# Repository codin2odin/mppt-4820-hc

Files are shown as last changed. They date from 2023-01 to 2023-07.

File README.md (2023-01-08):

# MPPT charge controller with HS load switch and CAN

 Development ongoing.

Schematic: [PDF file](build/mppt-4820-hc_schematic.pdf)

Bill of Materials: [CSV file](build/mppt-4820-hc_bom(hv_supply,can).csv)

Firmware repository: [charge-controller-firmware](https://github.com/codin2odin/charge-controller-firmware)

This charge controller design is modified version of [mppt-2420-hc](https://github.com/LibreSolar/mppt-2420-hc) with goal of adding support for 36v & 48v battery systems.

## Features

- Solar input terminal
    - Max. 85V (100V MOSFETs used)
    - DC/DC converter inductor current max. 20A
- Battery output terminal
    - 10 V - 60 V (supporting 12v & 24v & 36v & 48v battery systems)
    - Max. current: 20A (limited by inductor current)
- Load terminal: 20A
- New STM32G431 ARM MCU with advanced digital power conversion features
- Expandable via Olimex Universal Extension Connector (UEXT)
- Two bi-color (red/green) LEDs for status indication. Additional user interface can be included in separate PCB in front panel housing and connected via UEXT
- CAN interface via RJ45 connectors

## Mechanical design

- TO-220 MOSFETs can be screwed to large heat sink at the back

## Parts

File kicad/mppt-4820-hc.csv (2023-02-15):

Source: | /home/strigis/repositories/mppt-4820-hc/kicad/mppt-2420-hc.kicad_sch
Date: | Wed 25 Jan 2023 10:38:43 AM CET
Tool: | Eeschema 6.0.10-86aedd382b~118~ubuntu20.04.1
Generator: | /usr/share/kicad/plugins/bom_csv_grouped_by_value_with_fp.py
Component Count: | 141
Ref | Qnty | Value | Cmp name | Footprint | Description | Vendor
C1, C2, | 2 | 560µF | CP-LibreSolar | Capacitor_THT:CP_Radial_D18.0mm_P7.50mm
C3, C18, | 2 | 1µF | C | LibreSolar:C_0805_2012 | Unpolarized capacitor
C4, | 1 | 100nF | C | LibreSolar:C_0805_2012 | Unpolarized capacitor
C5, C27, | 2 | 680µF | CP-LibreSolar | Capacitor_THT:CP_Radial_D10.0mm_P5.00mm
C6, | 1 | 2.2nF | C | LibreSolar:C_0603_1608 | Unpolarized capacitor
C7, C9, C10, C13, C20, C22, C24, C29, C30, C31, C32, C48, | 12 | 100nF | C | LibreSolar:C_0603_1608 | Unpolarized capacitor
C8, C14, C16, C17, C25, C34, | 6 | 10nF | C | LibreSolar:C_0603_1608 | Unpolarized capacitor
C11, C15, | 2 | 1nF | C | LibreSolar:C_0603_1608 | Unpolarized capacitor
C12, C33, C39, C49, | 4 | 2.2µF | C | LibreSolar:C_0603_1608 | Unpolarized capacitor
C19, | 1 | 4.7µF | C | LibreSolar:C_1210_3225 | Unpolarized capacitor
C21, C23, | 2 | 10µF | C | LibreSolar:C_0805_2012 | Unpolarized capacitor
C40, | 1 | 1µF | C | LibreSolar:C_0603_1608 | Unpolarized capacitor
C41, | 1 | 4.7µF | C | LibreSolar:C_0603_1608 | Unpolarized capacitor
C42, C44, | 2 | 0.22µF | C-LibreSolar | Capacitor_THT:C_Rect_L7.2mm_W3.5mm_P5.00mm_FKS2_FKP2_MKS2_MKP2
D1, | 1 | SS16FP | D_Schottky | Diode_SMD:D_PowerDI-123 | Diode Schottky
D2, D6, | 2 | NRVTS260ESFT1G | D_Schottky-LibreSolar | Diode_SMD:D_SOD-123
D4, | 1 | BAS70-04 | BAS40-04 | Package_TO_SOT_SMD:SOT-23 | 40V 0.2A Dual Small Signal Schottky Diodes
D5, | 1 | 12V | D_Zener | Diode_SMD:D_SOT-23_ANK | Diode zener
D7, D14, D15, | 3 | SS14FL | D_Schottky | Diode_SMD:D_SOD-123 | Diode Schottky
D16, | 1 | 1N4148 | D | LibreSolar:D_SOD-123 | Diode
F1, | 1 | 25A | Fuse_PlugIn-LibreSolar | LibreSolar:NULL
F2, F3, | 2 | 500mA | Polyfuse_Small | Fuse:Fuse_1206_3216Metric | Resettable fuse, polymeric positive temperature coefficient, small symbol
FID1, FID2, FID3, | 3 | Fiducial | Fiducial | LibreSolar:Fiducial_0.7mm | Fiducial Marker
J1, J2, | 2 | MKDS 5/ 2-9,5 | Screw_Terminal_1x02 | LibreSolar:Phoenix_Contact_MKDS_5-2-9,5
J4, J5, | 2 | 8P8C | 8P8C | LibreSolar:RJ45_8P8C | RJ connector, 8P8C (8 positions 8 connected), RJ31/RJ32/RJ33/RJ34/RJ35/RJ41/RJ45/RJ49/RJ61
J7, | 1 | UEXT | UEXT | LibreSolar:Box_Header_2x05x2.54mm_Straight | Olimex UEXT connector (2x5 box header)
JP1, | 1 | Jumper_NC_Small | Jumper_NC_Small-LibreSolar | Connector_PinHeader_2.54mm:PinHeader_1x02_P2.54mm_Vertical
L1, | 1 | 53µH | L | LibreSolar:Inductor_Toroid_D32.8mm_4mm2 | Inductor
L2, | 1 | 4.7µH | L_Small | Inductor_SMD:L_0805_2012Metric | Inductor, small symbol
L3, | 1 | 47µH | L_Small | LibreSolar:Bourns_SRN6045TA | Inductor, small symbol
LED1, LED2, | 2 | LED_Dual_PLCC4 | LED_Dual_CACA_BackToBack-LibreSolar | LED_SMD:LED_Avago_PLCC4_3.2x2.8mm_CW
LOGO1, | 1 | LIBRE_SOLAR | LibreSolar_Logo | LibreSolar:LIBRESOLAR_LOGO
LOGO2, | 1 | OPEN_HARDWARE | Logo_Open_Hardware_Small | Symbol:OSHW-Logo_5.7x6mm_SilkScreen | Open Hardware logo, small
MK1, MK2, MK3, MK4, | 4 | Mounting_Hole | MountingHole | MountingHole:MountingHole_3.2mm_M3 | Mounting Hole without connection
P1, | 1 | CONN_01X02 | Conn_01x02 | Connector_PinHeader_2.54mm:PinHeader_1x02_P2.54mm_Vertical | Generic connector, single row, 01x02, script generated (kicad-library-utils/schlib/autogen/connector/)
Q1, Q2, Q3, | 3 | IPA045N10N3G | Q_NMOS_GDS | LibreSolar:TO-220-3_Horizontal_BottomHeatsink | N-MOSFET transistor, gate/drain/source
R1, R2, R3, R5, | 4 | 3R3 | R | LibreSolar:R_0805_2012 | Resistor
R4, R12, | 2 | 4R7 | R | LibreSolar:R_1206_3216 | Resistor
R6, | 1 | 2m | R | LibreSolar:R_Bourns_CRE2512 | Resistor
R7, R16, R24, R64, | 4 | 10k | R | LibreSolar:R_0603_1608 | Resistor
R11, | 1 | 120R | R-LibreSolar | Resistor_SMD:R_1206_3216Metric
R13, R17, R22, R30, | 4 | 100k | R | LibreSolar:R_0603_1608 | Resistor
R14, R20, R21, R31, | 4 | 2.2k | R | LibreSolar:R_0603_1608 | Resistor
R15, R56, | 2 | 1M | R | LibreSolar:R_0603_1608 | Resistor
R18, | 1 | 5.6k | R | LibreSolar:R_0603_1608 | Resistor
R23, | 1 | 33k | R | LibreSolar:R_0603_1608 | Resistor
R25, R26, R29, | 3 | 1k | R | LibreSolar:R_0603_1608 | Resistor
R27, R28, R32, R40, | 4 | 47R | R | LibreSolar:R_0603_1608 | Resistor
RT1, | 1 | 10k | Thermistor_NTC | Capacitor_THT:C_Disc_D3.8mm_W2.6mm_P2.50mm | Temperature dependent resistor, negative temperature coefficient
RV2, | 1 | 82V | Varistor | Varistor:RV_Disc_D12mm_W4.3mm_P7.5mm | Voltage dependent resistor
SWD1, | 1 | ST_Nucleo_SWD | ST_Nucleo_SWD_5p-LibreSolar | Connector_PinHeader_2.54mm:PinHeader_1x05_P2.54mm_Vertical
T1, T3, T10, | 3 | BC846B | BC846 | LibreSolar:SOT-23 | 0.1A Ic, 65V Vce, NPN Transistor, SOT-23
T4, | 1 | BC856B | BC856 | LibreSolar:SOT-23 | 0.1A Ic, 65V Vce, PNP Transistor, SOT-23
TP1, TP3, TP4, TP5, TP6, TP7, TP8, TP9, TP10, TP11, TP12, TP13, TP14, TP15, TP17, TP18, TP19, TP20, TP21, TP22, | 20 | 1.5mm | TestPoint | TestPoint:TestPoint_Pad_D1.5mm | test point
U1, | 1 | LM5107 | LM5107 | LibreSolar:SOIC-8_3.9x4.9mm_Pitch1.27mm
U2, | 1 | STM32G431CBTx | STM32G431CBTx-LibreSolar | Package_QFP:LQFP-48_7x7mm_P0.5mm
U3, | 1 | MPQ8112 | MPQ8112 | Package_TO_SOT_SMD:TSOT-23-6
U4, | 1 | LMR16006X | LMR16006 | LibreSolar:SOT-23-6 | SIMPLE SWITCHER® 4V to 60V, 600mA Step-Down Regulator with Low Iq
U6, | 1 | W25Q80DVS | W25Q128JVS | LibreSolar:SOIC-8_3.9x4.9mm_Pitch1.27mm | 128Mb Serial Flash Memory, Standard/Dual/Quad SPI, SOIC-8
U7, | 1 | TCAN334 | TCAN334 | LibreSolar:SOIC-8_3.9x4.9mm_Pitch1.27mm | High-Speed CAN Transceiver, 1Mbps, 3.3V supply, low power standby mode, shutdown mode, SOT-23-8/SOIC-8
XF1, | 1 | Fuse_Holder | Fuse_Holder-LibreSolar | LibreSolar:Eaton_S-4000
Y1, | 1 | 8MHz | Resonator | LibreSolar:Resonator_Murata_CSTNE | Two pin crystal

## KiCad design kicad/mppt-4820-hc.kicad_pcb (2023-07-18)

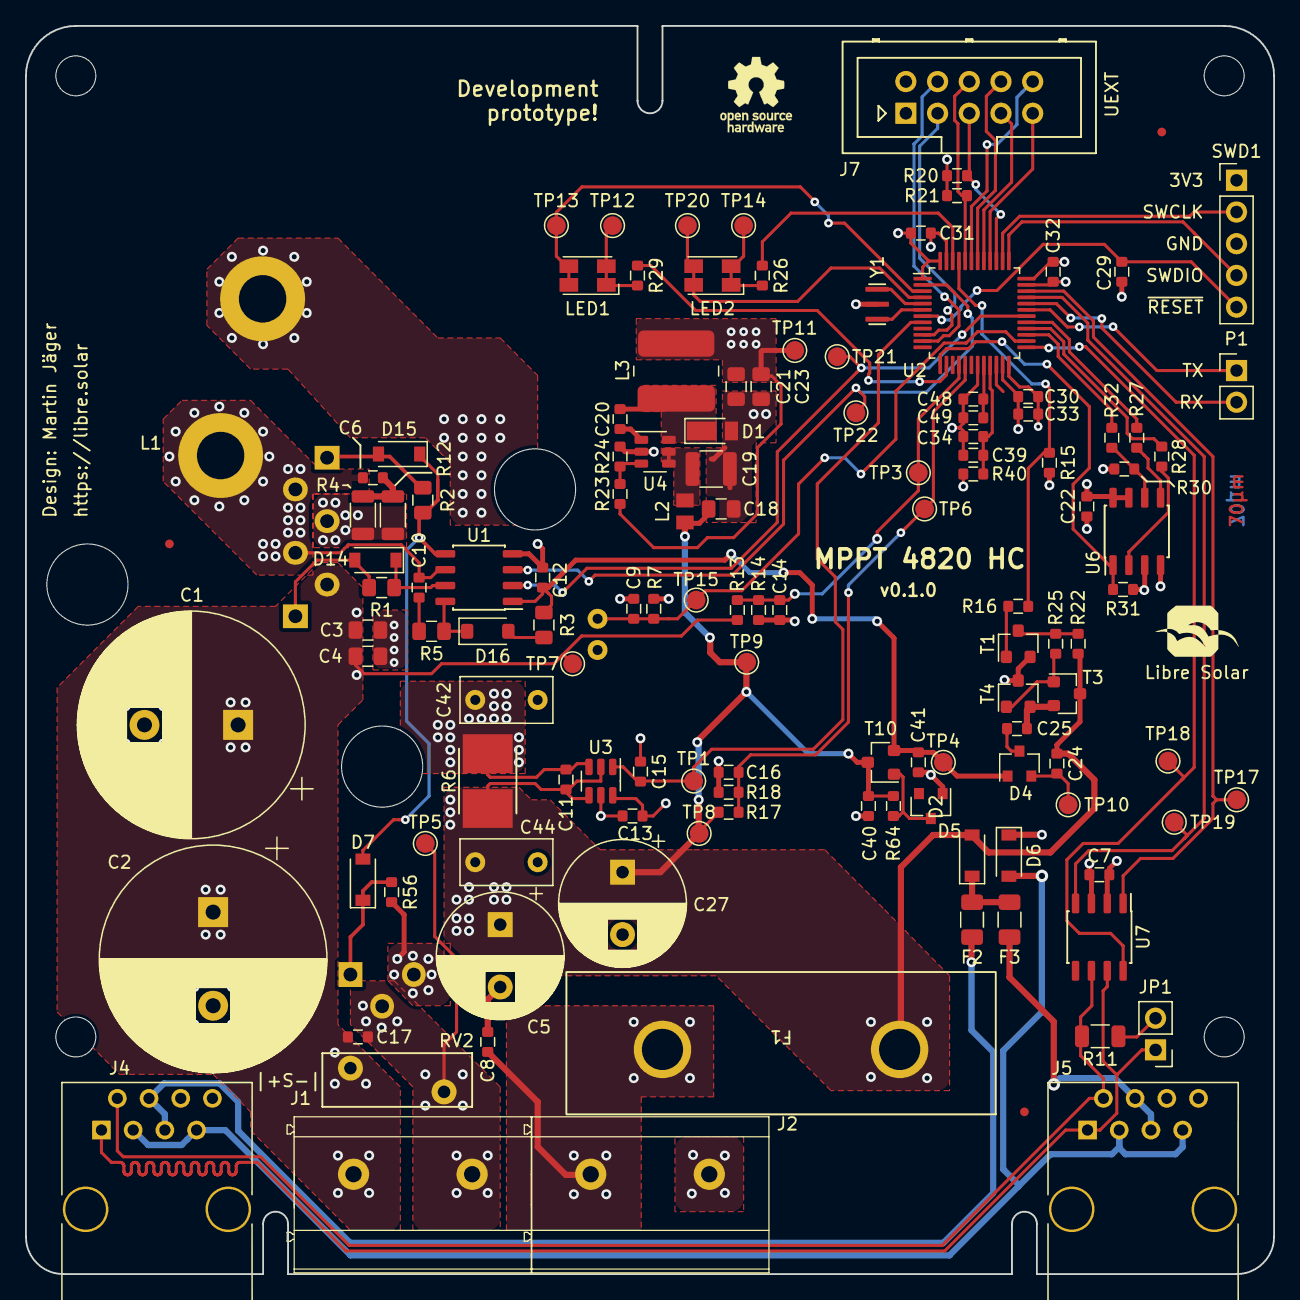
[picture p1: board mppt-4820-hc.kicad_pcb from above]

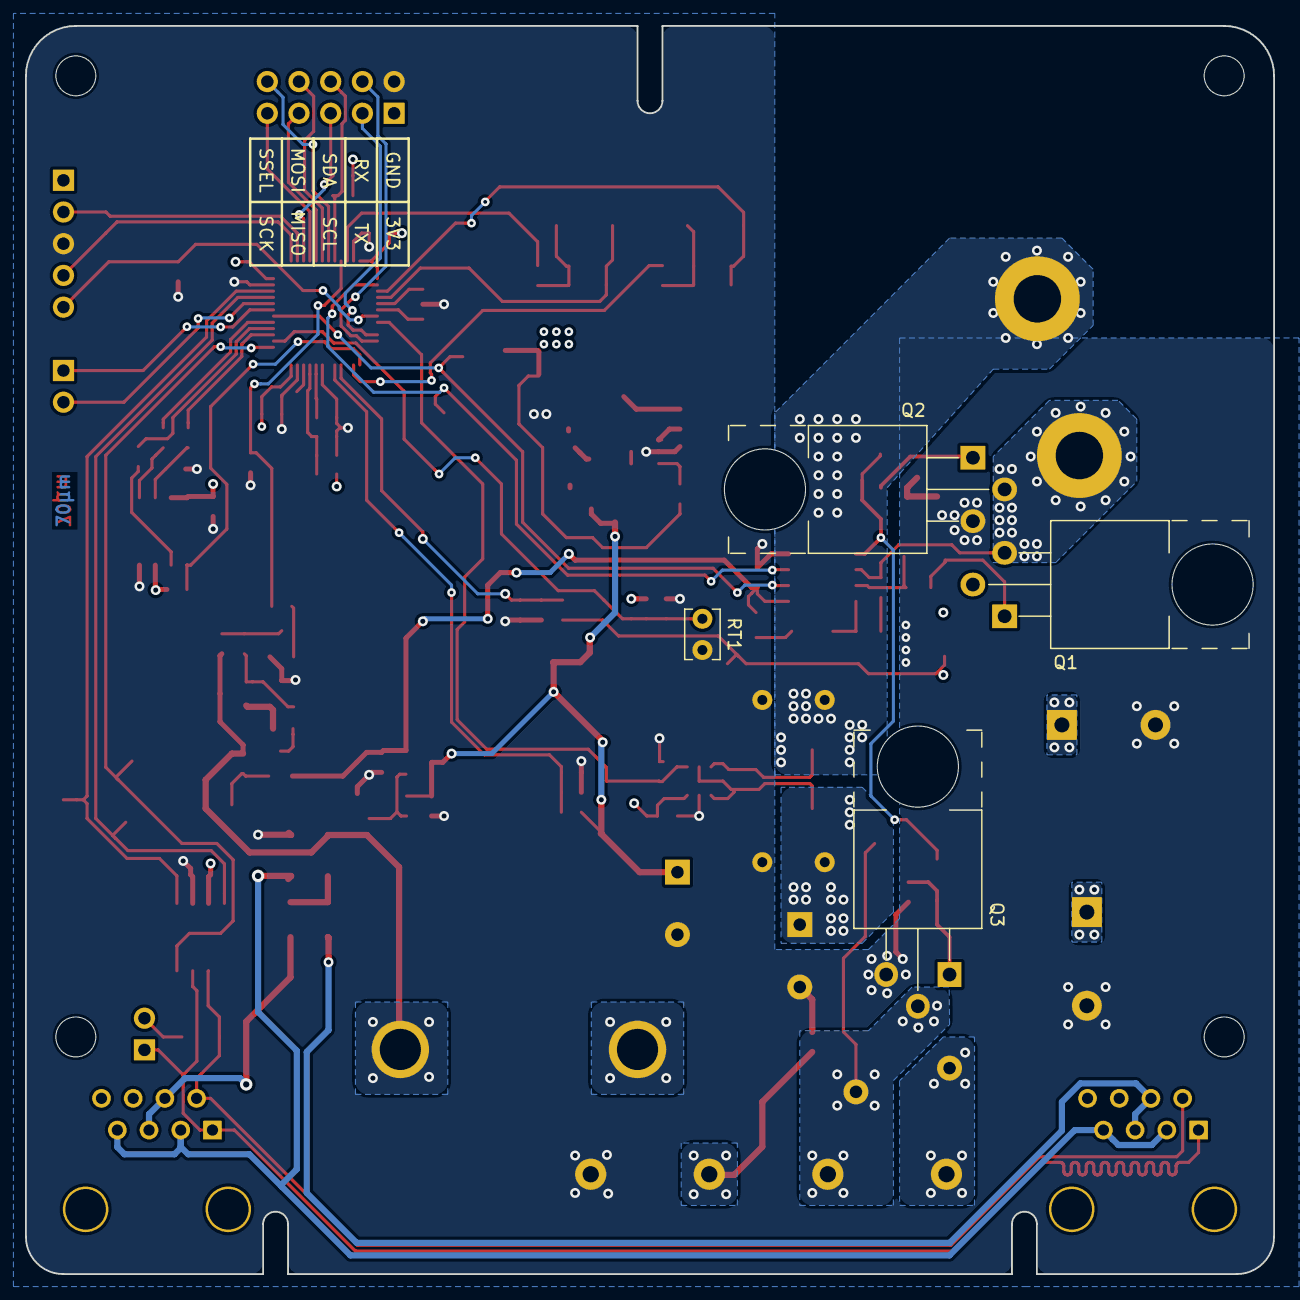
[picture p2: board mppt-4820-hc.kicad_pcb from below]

Board: 4 copper layers, 100.0 x 100.0 mm, 140 parts (4 on the bottom side), 76 nets.

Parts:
C1, C2: 560µF; CP_Radial_D18.0mm_P7.50mm
C3, C18: 1µF; C_0805_2012
C4: 100nF; C_0805_2012
C5, C27: 680µF; CP_Radial_D10.0mm_P5.00mm
C6: 2.2nF; C_0603_1608
C7, C9, C10, C13, C20, C22, C24, C29, C30, C31, C32, C48: 100nF; C_0603_1608
C8, C14, C16, C17, C25, C34: 10nF; C_0603_1608
C11, C15: 1nF; C_0603_1608
C12, C33, C39, C49: 2.2µF; C_0603_1608
C19: 4.7µF; C_1210_3225
C21, C23: 10µF; C_0805_2012
C40: 1µF; C_0603_1608
C41: 4.7µF; C_0603_1608
C42, C44: 0.22µF; C_Rect_L7.2mm_W3.5mm_P5.00mm_FKS2_FKP2_MKS2_MKP2
D1: SS16FP; D_PowerDI-123
D2, D6: NRVTS260ESFT1G; D_SOD-123
D4: BAS70-04; SOT-23
D5: 12V; D_SOT-23_ANK
D7, D14, D15: SS14FL; D_SOD-123
D16: 1N4148; D_SOD-123
F1: 25A; Eaton_S-4000
F2, F3: 500mA; Fuse_1206_3216Metric
FID1, FID2, FID3: Fiducial; Fiducial_0.7mm
J1, J2: MKDS 5/ 2-9,5; Phoenix_Contact_MKDS_5-2-9,5
J4, J5: 8P8C; RJ45_8P8C
J7: UEXT; Box_Header_2x05x2.54mm_Straight
JP1: Jumper_NC_Small; PinHeader_1x02_P2.54mm_Vertical
L1: 53µH; Inductor_Toroid_D32.8mm_4mm2
L2: 4.7µH; L_0805_2012Metric
L3: 47µH; Bourns_SRN6045TA
LED1, LED2: LED_Dual_PLCC4; LED_Avago_PLCC4_3.2x2.8mm_CW
LOGO1: LIBRE_SOLAR; LIBRESOLAR_LOGO
LOGO2: OPEN_HARDWARE; OSHW-Logo_5.7x6mm_SilkScreen
MK1, MK2, MK3, MK4: Mounting_Hole; MountingHole_3.2mm_M3
P1: CONN_01X02; PinHeader_1x02_P2.54mm_Vertical
Q1, Q2, Q3: IPA045N10N3G; TO-220-3_Horizontal_BottomHeatsink
R1, R2, R3, R5: 3R3; R_0805_2012
R4, R12: 4R7; R_1206_3216
R6: 2m; R_Bourns_CRE2512
R7, R16, R24, R64: 10k; R_0603_1608
R11: 120R; R_1206_3216Metric
R13, R17, R22, R30: 100k; R_0603_1608
R14, R20, R21, R31: 2.2k; R_0603_1608
R15, R56: 1M; R_0603_1608
R18: 5.6k; R_0603_1608
R23: 33k; R_0603_1608
R25, R26, R29: 1k; R_0603_1608
R27, R28, R32, R40: 47R; R_0603_1608
RT1: 10k; C_Disc_D3.8mm_W2.6mm_P2.50mm
RV2: 82V; RV_Disc_D12mm_W4.3mm_P7.5mm
SWD1: ST_Nucleo_SWD; PinHeader_1x05_P2.54mm_Vertical
T1, T3, T10: BC846B; SOT-23
T4: BC856B; SOT-23
TP1, TP3, TP4, TP5, TP6, TP7, TP8, TP9, TP10, TP11, TP12, TP13, TP14, TP15, TP17, TP18, TP19, TP20, TP21, TP22: 1.5mm; TestPoint_Pad_D1.5mm
U1: LM5107; SOIC-8_3.9x4.9mm_Pitch1.27mm
U2: STM32G431CBTx; LQFP-48_7x7mm_P0.5mm
U3: MPQ8112; TSOT-23-6
U4: LMR16006X; SOT-23-6
U6: W25Q80DVS; SOIC-8_3.9x4.9mm_Pitch1.27mm
U7: TCAN334; SOIC-8_3.9x4.9mm_Pitch1.27mm
Y1: 8MHz; Resonator_Murata_CSTNE

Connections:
+3V3: C7.1, C13.1, C21.1, C22.1, C23.1, C30.1, C31.1, C32.1, C33.1, J7.1 (3V3), L3.2, R7.1, R20.2, R21.2, R23.1, R31.2, R40.2, SWD1.1 (VCC), TP11.1, U2.1 (VBAT), U2.24 (VDD), U2.36 (VDD), U2.48 (VDD), U3.6 (EN), U6.3 (IO2), U6.7 (IO3), U6.8 (VCC), U7.3 (VCC)
+12V: C12.1, C41.1, D4.1, R3.2, T10.2 (E), TP4.1, U1.1 (VDD)
/BAT+: C8.1, F1.2, J2.1
/CAN/CAN_PWR1: F2.1, J4.4, J4.5
/CAN/CAN_PWR2: F3.1, J5.4, J5.5
/CAN/CAN_RX: TP19.1, U2.33 (PA11), U7.4 (RXD)
/CAN/CAN_STB: TP18.1, U2.25 (PB11), U7.8 (STB)
/CAN/CAN_TX: TP17.1, U2.34 (PA12), U7.1 (TXD)
/CAN_GND: D6.2 (A), J4.3, J4.7, J5.3, J5.7
/CAN_H: J4.1, J5.1, JP1.1, U7.7 (CANH)
/CAN_L: J4.2, J5.2, R11.2, U7.6 (CANL)
/DC/DC/HS_DRV: D14.1 (K), R1.2, U1.7 (HO)
/DC/DC/I_DCDC: C15.1, TP1.1, U2.8 (PA0), U3.1 (OUT)
/DC/DC/LS_DRV: D7.2 (A), D15.1 (K), R2.2, U1.5 (LO)
/DC/DC/PWM_HS: TP21.1, U1.2 (HI), U2.30 (PA8)
/DC/DC/PWM_LS: TP22.1, U1.3 (LI), U2.2 (PC13)
/DC/DC/SHUNT_DCDC_P: C11.1, C42.1, L1.2, R6.2, U3.3 (+)
/DC/DC/SW_NODE: C6.1, C10.2, L1.1, Q1.3 (S), Q2.2 (D), U1.6 (HS)
/DC/DC/V_DCDC_H: C14.1, R13.2, R14.1, TP3.1, U2.16 (PB0)
/DC/DC/V_DCDC_L: C16.1, R17.2, R18.1, TP6.1, U2.17 (PB1)
/DCDC_HV+: C1.1, C2.1, C3.1, C4.1, C17.1, J1.1, Q1.2 (D), R13.1, RV2.1, TP7.1
/DCDC_HV-: C17.2, J1.2, Q3.2 (D), RV2.2, TP5.1
/MCU/ADC1_IN11: C9.1, R7.2, RT1.1, TP15.1, U2.26 (PB12)
/MCU/GPIOC_14: LED1.2 (K1), LED1.3 (A2), TP13.1, U2.3 (PC14-OSC32_IN)
/MCU/GPIOC_15: LED2.2 (K1), LED2.3 (A2), TP20.1, U2.4 (PC15-OSC32_OUT)
/MCU/I2C1_SCL: J7.5 (SCL), R20.1, U2.39 (PA15)
/MCU/I2C1_SDA: J7.6 (SDA), R21.1, U2.44 (PB7)
/MCU/OSC_IN: U2.5 (PF0-OSC_IN), Y1.3
/MCU/OSC_OUT: U2.6 (PF1-OSC_OUT), Y1.1
/MCU/SPI1_MISO: J7.7 (MISO), U2.41 (PB4)
/MCU/SPI1_MOSI: J7.8 (MOSI), U2.42 (PB5)
/MCU/SPI1_SCK: J7.9 (SCK), U2.40 (PB3)
/MCU/SPI1_SSEL: J7.10 (SSEL), U2.43 (PB6)
/MCU/SPI2_CS: R31.1, U2.13 (PA5), U6.1 (~CS)
/MCU/SPI2_MISO: R28.1, U2.28 (PB14)
/MCU/SPI2_MOSI: R27.1, U2.29 (PB15)
/MCU/SPI2_SCK: R32.2, U2.27 (PB13)
/MCU/SWCLK: SWD1.2 (SWCLK), U2.38 (PA14)
/MCU/SWDIO: SWD1.4 (SWDIO), U2.37 (PA13)
/MCU/TIM8_CH2: R15.2, R16.2, U2.45 (PB8-BOOT0)
/MCU/TIM16_CH1: R29.2, U2.14 (PA6)
/MCU/TIM17_CH1: R26.2, U2.46 (PB9)
/MCU/USART1_RX: P1.2, U2.32 (PA10)
/MCU/USART1_TX: P1.1, U2.31 (PA9)
/MCU/USART2_RX: J7.4 (RXD), U2.11 (PA3)
/MCU/USART2_TX: J7.3 (TXD), U2.10 (PA2)
/MCU/~RESET: C29.1, SWD1.5 (NRST), U2.7 (NRST)
/Power supply/CP_OUT: C24.1, D4.2, TP10.1
/Power supply/CP_SW: C25.2, T3.2 (E), T4.2 (E)
GND: C1.2, C2.2, C3.2, C4.2, C5.2, C7.2, C8.2, C9.2, C12.2, C13.2, C14.2, C15.2, C16.2, C18.2, C19.2, C21.2, C22.2, C23.2, C27.2, C29.2, C30.2, C31.2, C32.2, C33.2, C34.2, C39.2, C40.2, C41.2, C42.2, C44.1, C48.2, C49.2, D1.2 (A), D5.2 (A), D6.1 (K), J2.2, J7.2 (GND), Q2.3 (S), Q3.3 (S), R4.1, R12.1, R14.2, R15.1, R18.2, R24.2, R30.1, R56.2, RT1.2, SWD1.3 (GND), T1.2 (E), T4.3 (C), U1.4 (VSS), U2.19 (VSSA), U2.23 (VSS), U2.35 (VSS), U2.47 (VSS), U3.5 (GND), U4.2 (GND), U6.4 (GND), U7.2 (GND), Y1.2
unnamed: C6.2, R4.2, R12.2
unnamed: C10.1, R5.2
unnamed: C25.1, D4.3
unnamed: C20.2, D1.1 (K), L3.1, U4.6 (SW)
unnamed: D2.1 (K), F2.2, F3.2
unnamed: D5.1 (K), R64.1, T10.1 (B)
unnamed: D7.1 (K), Q3.1 (G), R56.1
unnamed: D14.2 (A), Q1.1 (G), R1.1
unnamed: D15.2 (A), Q2.1 (G), R2.1
unnamed: D16.2 (A), R3.1
unnamed: D16.1 (K), R5.1, U1.8 (HB)
unnamed: JP1.2, R11.1
unnamed: LED1.1 (A1), LED1.4 (K2), R29.1, TP12.1
unnamed: LED2.1 (A1), LED2.4 (K2), R26.1, TP14.1
unnamed: R16.1, T1.1 (B)
unnamed: R22.1, R25.1, T1.3 (C)
unnamed: R25.2, T3.1 (B), T4.1 (B)
unnamed: C20.1, U4.1 (CB)
unnamed: C19.1, L2.2, U4.4 (EN), U4.5 (Vin)
unnamed: R23.2, R24.1, U4.3 (FB)
unnamed: R30.2, R32.1, U6.6 (CLK)
unnamed: R27.2, U6.5 (DI(IO0))
unnamed: R28.2, U6.2 (DO(IO1))
VBUS: C5.1, C11.2, C18.1, C24.2, C27.1, C40.1, C44.2, D2.2 (A), F1.1, L2.1, R6.1, R17.1, R22.2, R64.2, T3.3 (C), T10.3 (C), TP8.1, TP9.1, U3.2 (-), U3.4 (V+)
VDDA: C34.1, C39.1, R40.1, U2.21 (VDDA)
VREF: C48.1, C49.1, U2.20 (VREF+)

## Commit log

2023-01-07 initial 48v LV side kicad update:
    migrated files to KiCad 6
    replaced LV side current amp ic (60v)
    replaced caps in LV (63v)
    removed HV rail supply option
    [can.kicad_sch, can.sch, dcdc.kicad_sch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]
2023-01-07 bom & schematic files updates
    [mppt-2420-hc_bom_(hv_supply,can).csv, mppt-2420-hc_bom_mechanical.csv, mppt-4820-hc_bom(hv_supply,can).csv]
2023-01-08 updated inline 6.3x32 fuse holder in bom
    [mppt-4820-hc_bom(hv_supply,can).csv]
2023-01-14 removed load terminal & circuit
    [can.kicad_sch, load-switch.kicad_sch, mppt-2420-hc.kicad_pcb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]
2023-01-14 kicad files cleanup
2023-01-14 major changes
    removed Load terminal
    changed to 6.3x32mm fuse pcb holder
    added LibreSolar kicad footprint library locally
    [dcdc.kicad_sch, mppt-2420-hc.kicad_pcb, mppt-2420-hc.kicad_sch]
2023-01-18 minor component name fix
    [mppt-2420-hc.kicad_pcb, mppt-2420-hc.kicad_sch]
2023-02-15 pcb minor fixes, updated bom files, updated project name
    [can.kicad_sch, dcdc.kicad_sch, mcu.kicad_sch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]
2023-05-04 minor fixes & cleanup
    [mppt-4820-hc.kicad_pcb]
2023-07-14 updated project to kicad 7
    [can.kicad_sch, dcdc.kicad_sch, mcu.kicad_sch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]
2023-07-18 some DRC check errors fixes (prototype 1)
    [mppt-4820-hc.kicad_pcb, mppt-4820-hc.kicad_sch]

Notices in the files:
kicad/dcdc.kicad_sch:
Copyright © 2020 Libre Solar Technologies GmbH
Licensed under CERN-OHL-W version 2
